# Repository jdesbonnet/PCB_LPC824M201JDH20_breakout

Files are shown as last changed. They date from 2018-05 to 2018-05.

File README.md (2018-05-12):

# PCB_LPC824M201JDH20_breakout

Breakout board for TSSOP package version of LPC824 ARM Cortex-M0+ MCU. 

Features:

 * Extra long IC pin leads which makes handsoldering easier.
 * Option for crystal + 2C mounted underside. Crystal component height needs to be 2mm or less.
 * Option for one or two bypass 0602 capacitors (right above the IC).
 * Option for 0602 LED + R on PIO0_23 (package pin 1).
 
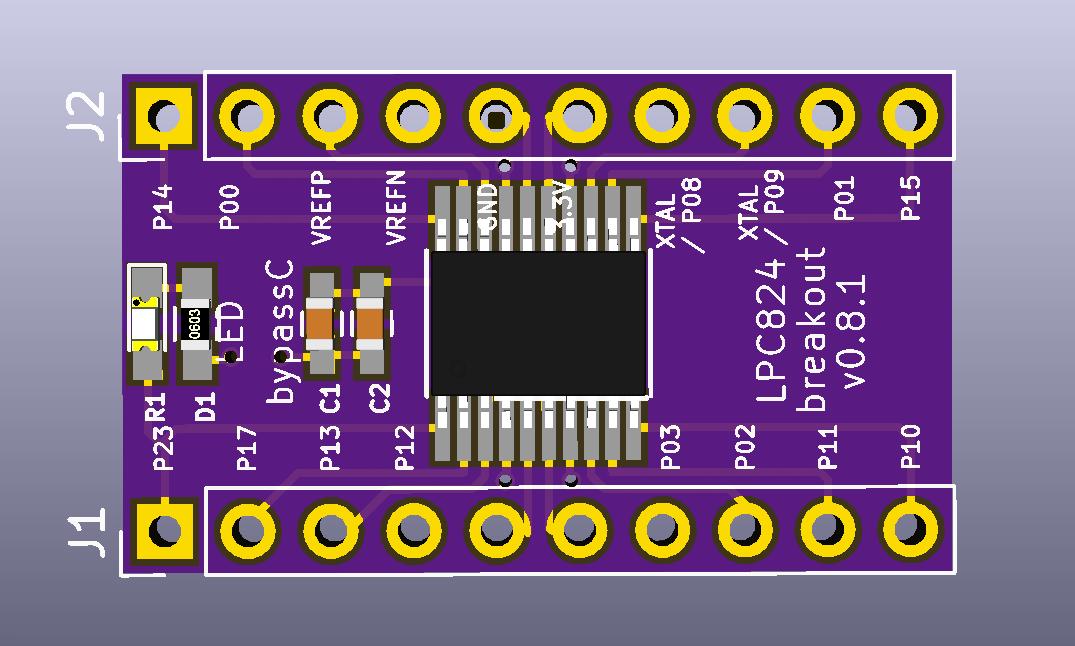
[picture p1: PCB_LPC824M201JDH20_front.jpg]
3D render front

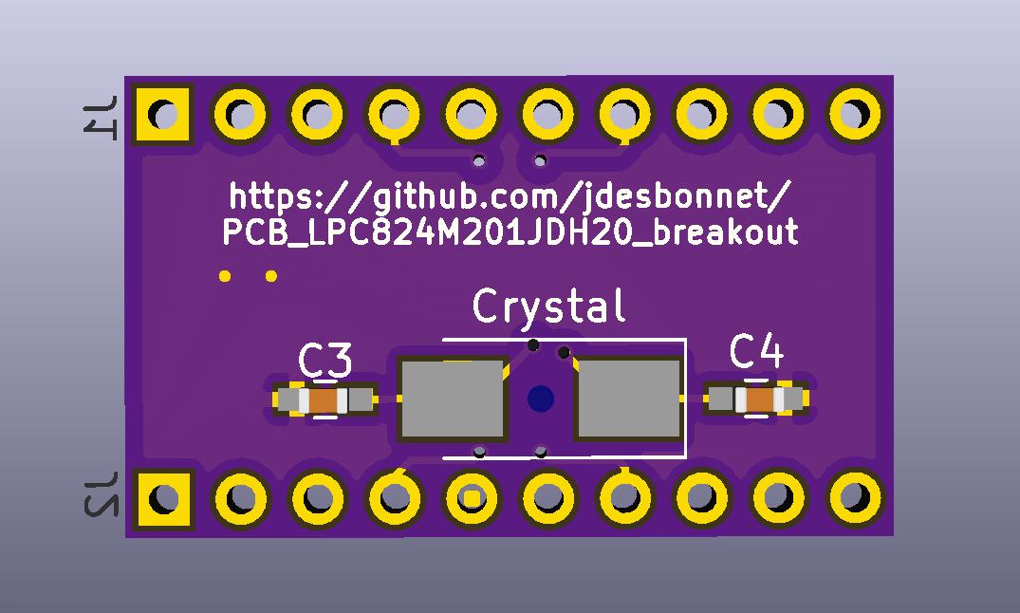
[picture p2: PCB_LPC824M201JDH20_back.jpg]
3D render back

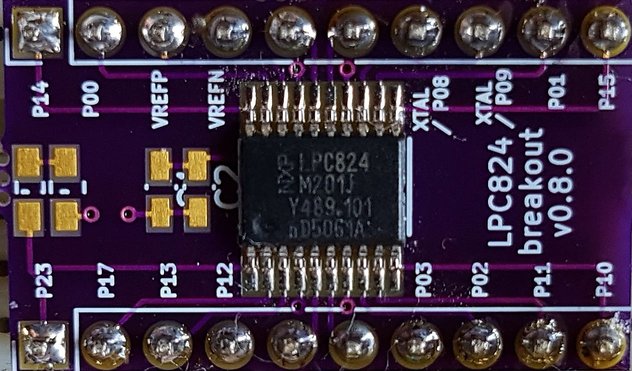
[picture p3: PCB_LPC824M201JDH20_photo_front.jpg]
photo front


## History

Version 0.8.1, 2018-05-12

Changes to silk screen layer to make purpose of passive components clearer. 
Add link to project git repo.

Version 0.8.0, 2018-04-24

Sent to OSHPark.com for fabrication. PCB arrived 2018-05-11. Works as expected. Only thing I'd change is 
marking the optional bypass and LED pads more clearly. I haven't tested the crystal.

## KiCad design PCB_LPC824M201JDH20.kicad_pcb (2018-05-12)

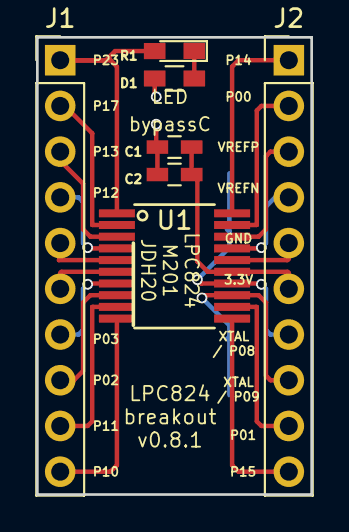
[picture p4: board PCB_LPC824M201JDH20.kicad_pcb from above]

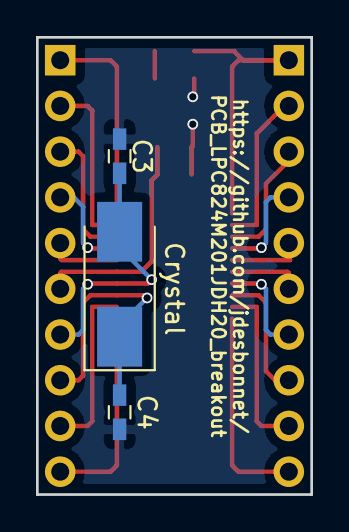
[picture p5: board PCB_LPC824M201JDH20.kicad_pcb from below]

Board: 2 copper layers, 15.2 x 25.4 mm, 10 parts (3 on the bottom side), 21 nets.

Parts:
C1, C2, C3, C4: C; C_0603_HandSoldering
Crystal: Crystal; Crystal_SMD_0603-2pin_6.0x3.5mm_HandSoldering
D1: LED; LED_0603_HandSoldering
J1, J2: Conn_01x10; Pin_Header_Straight_1x10_Pitch2.54mm
R1: R; R_0603_HandSoldering
U1: LPC824M201JDH20; TSSOP-20_4.4x6.5mm_Pitch0.65mm

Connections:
3.3V: C1.1, C2.1, J2.6, U1.15
GND: C1.2, C2.2, C3.1, C4.1, J2.5, R1.1, U1.16
LED: D1.2, J1.1, U1.1
unnamed: D1.1, R1.2
PIO0_0: J2.2, U1.19
PIO0_1: J2.9, U1.12
PIO0_2: J1.8, U1.8
PIO0_3: J1.7, U1.7
PIO0_4: J1.6, U1.6
PIO0_5: J1.5, U1.5
PIO0_10: J1.10, U1.10
PIO0_11: J1.9, U1.9
PIO0_12: J1.4, U1.4
PIO0_13: J1.3, U1.3
PIO0_14: J2.1, U1.20
PIO0_15: J2.10, U1.11
PIO0_17: J1.2, U1.2
VREFN: J2.4, U1.17
VREFP: J2.3, U1.18
XTALIN: C3.2, Crystal.2, J2.7, U1.14
XTALOUT: C4.2, Crystal.1, J2.8, U1.13

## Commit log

2018-04-22 no comment
    [PCB_LPC824M201JDH20.kicad_pcb, PCB_LPC824M201JDH20.sch]
2018-05-12 ground pour
    [PCB_LPC824M201JDH20.kicad_pcb]
2018-05-12 fix front silkscreen
    [PCB_LPC824M201JDH20.kicad_pcb]
2018-05-12 fix back silkscreen, add URL to github repo
    [PCB_LPC824M201JDH20.kicad_pcb]
